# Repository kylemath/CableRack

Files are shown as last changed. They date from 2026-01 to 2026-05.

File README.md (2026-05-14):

# Modular Cable Organizer + Universal Connector System

A wall-mountable, modular cable organizer system designed for 3D printing (PLA+), with an experimental **Universal 24-Pin Connector System** for standardized cable interconnects.

## Project Structure

```
CableRack/
├── parameters.scad           # Central configuration (dimensions, tolerances)
├── insert_base.scad          # Base insert module with snap tabs
├── frame_single.scad         # Single-slot test frame
├── print_frame_2x2.scad      # 2x2 frame (4 slots) - PRODUCTION
├── print_frame_3x3.scad      # 3x3 frame (9 slots) - PRODUCTION
├── print_frame_wall_test.scad          # Wall thickness validation
├── print_frame_validation_test.scad    # Comprehensive test suite
├── insert_*.scad             # All connector insert types
├── print_insert_*.scad       # Print files for each insert
├── demo.scad                 # Demo view with all inserts
│
│── UNIVERSAL CONNECTOR SYSTEM (Experimental)
├── UNIVERSAL_CONNECTOR_SPEC.md    # Full 24-pin specification
├── insert_universal_base.scad     # Universal adapter base module
├── print_insert_universal_*.scad  # Universal adapter print files
├── print_universal_male_terminator.scad  # Cable-end connector
├── demo_universal.scad            # Universal system visualization
│
├── print/                    # Pre-generated STL files
├── ReferenceImages/          # Design reference blueprints
├── UPDATES.md                # Recent changes and improvements
└── README.md                 # This file
```

## Development Status

### ✅ Phase 1-4: COMPLETED
- [x] Parameters system with tolerances
- [x] Snap-fit mechanism with tabs
- [x] Single-slot test frame
- [x] Multi-slot parametric grid frames (2x2, 3x3)
- [x] Wall mounting holes with countersinks
- [x] Complete insert library (9 connector types)
- [x] Production-ready print files

### 🎯 Current Features
- **Frames**: Single (1x1), 2x2 (4 slots), 3x3 (9 slots)
- **Strong walls**: 2.4mm between slots (6 layers @ 0.4mm nozzle)
- **Inserts**: USB-C, USB-A, USB-Mini, USB-Micro, USB-B, Lightning, HDMI, 3.5mm jack, Blank/Label
- **Wall mounting**: 4-corner screw holes with countersinks
- **Snap-fit retention**: Tool-free insert installation/removal

## Print Settings (Recommended)

| Setting | Value |
|---|---|
| Material | PLA+ |
| Layer Height | 0.2mm |
| Nozzle | 0.4mm |
| Infill | 20-30% |
| Walls | 3 perimeters |
| Supports | None needed |

## Production Printing

### Ready-to-Print Files

Pre-generated STL files are in the `print/` directory:

**Frames:**
- `print_frame_single.stl` - 1x1 single slot (test frame)
- `print_frame_2x2.stl` - 2x2 grid (4 slots) - **Most common**
- `print_frame_3x3.stl` - 3x3 grid (9 slots) - NEW

**Inserts:** (9 types)
- `print_insert_usbc.stl` - USB Type-C
- `print_insert_usba.stl` - USB Type-A
- `print_insert_usb_mini.stl` - USB Mini
- `print_insert_micro.stl` - USB Micro
- `print_insert_usb_b.stl` - USB Type-B
- `print_insert_lightning.stl` - Apple Lightning
- `print_insert_hdmi.stl` - HDMI
- `print_insert_audio_jack.stl` - 3.5mm audio jack
- `print_insert_blank.stl` - Blank/label insert

### Test & Validation Files

Before printing production parts, validate with test files:

**Wall Thickness Test** (`print_frame_wall_test.scad`)
- Small print showing 2.4mm wall between slots
- Validates structural strength
- Quick print (~10 min)

**Comprehensive Validation** (`print_frame_validation_test.scad`)
- Wall cross-section view
- Insert fit test with clearances
- Frame size comparison (1x1, 2x2, 3x3)
- Uncomment desired test in file

### Generating STL Files

If you modify the design, regenerate STL files:

```bash
# Using OpenSCAD GUI: File > Export > STL
# Or from terminal:
cd /path/to/CableRack
openscad -o print/print_frame_2x2.stl print_frame_2x2.scad
openscad -o print/print_frame_3x3.stl print_frame_3x3.scad
# etc...
```

### Print Orientation

**Frames**: Print with back (flat) side down
- No supports needed
- Mounting hole countersinks on bottom
- Optimal layer adhesion for strength

**Inserts**: Print with port opening down
- Base plate prints first for dimensional accuracy
- Snap tabs print cleanly
- No supports needed

## Key Dimensions

| Parameter | Value | Description |
|---|---|---|
| Slot size | 32mm × 16mm | Interior frame slot (2:1 aspect) |
| Insert base | 31.4mm × 15.4mm | With 0.3mm clearance |
| **Frame wall** | **2.4mm** | **Between slots (6 layers @ 0.4mm nozzle)** |
| Frame depth | 6mm | Z height (2mm back + 4mm slot) |
| Insert body | 12-16mm | Varies by connector type |
| Clearance | 0.3mm | Standard FDM tolerance |
| Border | 8mm | Frame border with mounting holes |

## Viewing in OpenSCAD

**Demo Visualization** (`demo.scad`)
- Shows 2x2 frame with 4 different inserts
- Displays all 9 insert types in a 3x3 grid
- Toggle `show_cutaway = true` for cross-section view
- Color-coded inserts for easy identification

**Test Files**
- `print_frame_wall_test.scad` - Wall thickness validation
- `print_frame_validation_test.scad` - Multiple test views

## Recent Updates

See `UPDATES.md` for recent changes, including:
- Frame wall thickness increased to 2.4mm (6 layers @ 0.4mm nozzle)
- New 3x3 frame option
- Comprehensive test files for validation
- Improved parametric frame system

---

## Universal Connector System (Experimental)

An ambitious extension to the cable organizer that creates a **standardized 24-pin interconnect** allowing any cable to connect to any device through modular adapters.

### Concept

```
┌─────────────┐     ┌──────────────────┐     ┌─────────────┐
│   DEVICE    │────▶│  24-PIN UNIVERSAL│◀────│   CABLE     │
│  (Laptop)   │     │    INTERFACE     │     │  (Any type) │
└─────────────┘     └──────────────────┘     └─────────────┘
```

### Components

| Component | Description |
|---|---|
| **Device Adapter Insert** | Accepts original connector (USB-C, HDMI, etc.), routes to 24-pin rear |
| **Universal Male Terminator** | Replaces proprietary cable ends with standardized 24-pin plug |
| **Pass-Through Insert** | 24-pin female-to-female for cable extension |

### Protocol Support

| Protocol | Support Level | Notes |
|---|---|---|
| USB 2.0 | ✅ Full | Direct passive routing |
| USB 3.0/3.1 | ✅ Full | Requires impedance-matched PCB |
| USB-C PD (100W) | ✅ Full | With PD controller IC |
| DisplayPort 1.4 | ✅ Full | Native routing, 4 lanes |
| HDMI 1.4 | ⚠️ Active | Requires TMDS↔DP converter |
| Lightning | ✅ Full | USB 2.0 internally |
| 3.5mm Audio | ✅ Full | Analog passthrough |

### Files

- `UNIVERSAL_CONNECTOR_SPEC.md` - Complete 24-pin specification with pinout
- `insert_universal_base.scad` - Base module for all universal adapters
- `print_insert_universal_usbc.scad` - USB-C adapter
- `print_insert_universal_hdmi.scad` - HDMI adapter (active)
- `print_insert_universal_displayport.scad` - DisplayPort adapter
- `print_universal_male_terminator.scad` - Cable-end connector
- `demo_universal.scad` - Visualization and cross-sections

### Certification Path

For production: UL 62368-1, IEC 62368-1, FCC Part 15, CE Mark, RoHS

See `UNIVERSAL_CONNECTOR_SPEC.md` for full technical details.

---

## License

Personal/educational use.

## Preview

<p align="center">
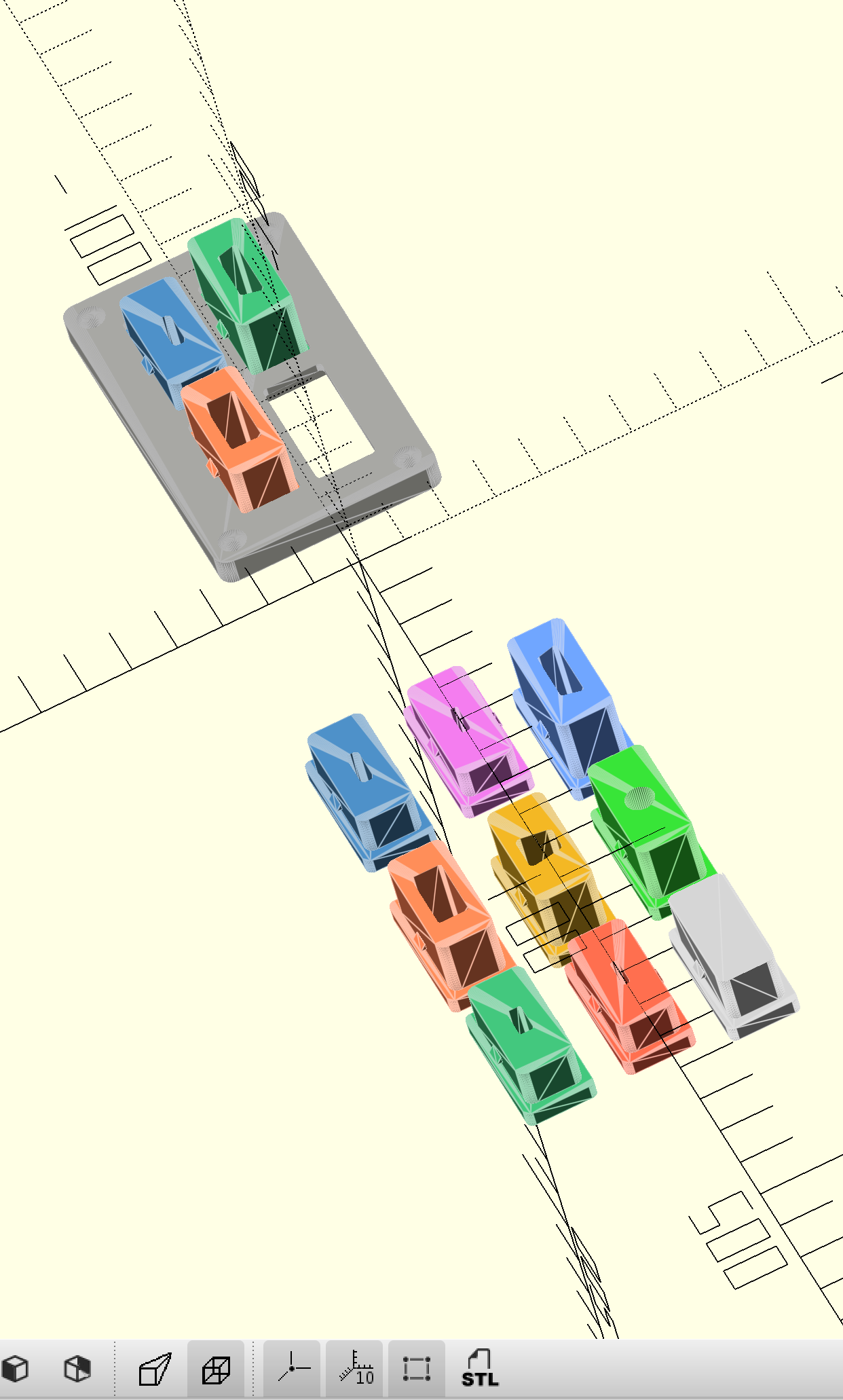
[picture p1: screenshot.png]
Project screenshot
  
</p>

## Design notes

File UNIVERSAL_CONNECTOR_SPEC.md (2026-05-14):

# Universal Connector System Specification

## Vision

A standardized 24-pin interconnect system that enables any cable to connect to any device through modular adapters. Built on the CableRack insert form factor.

## System Overview

```
┌─────────────────┐     ┌─────────────────┐     ┌─────────────────┐
│   DEVICE        │     │   UNIVERSAL     │     │   CABLE         │
│   (Laptop,      │────▶│   24-PIN        │◀────│   (USB-C,       │
│    Phone, TV)   │     │   INTERFACE     │     │    HDMI, etc.)  │
└─────────────────┘     └─────────────────┘     └─────────────────┘
        │                       │                       │
        ▼                       ▼                       ▼
  Original Port          Adapter Insert          Universal Male
  (unchanged)            with routing PCB         Terminator
```

### Components

| Component | Description |
|---|---|
| **Device Adapter Insert** | Accepts original male connector, routes to 24-pin rear interface |
| **Universal Male Terminator** | Replaces proprietary cable ends with standardized 24-pin plug |
| **Pass-Through Insert** | 24-pin female-to-female for cable extension |

---

## 24-Pin Interface Specification

### Physical Dimensions

```
Connector Housing: 16mm × 6mm × 4mm (fits in insert rear)
Pin Pitch: 1.27mm (0.05") - standard fine-pitch
Pin Array: 2 rows × 12 pins
Contact Type: Spring-loaded pogo pins (female) / Gold-plated pads (male)
Insertion Force: <3N
Rated Cycles: 10,000+
```

### Pin Layout (View from rear of insert, looking at female connector)

```
        ┌─────────────────────────────────────────────────────┐
        │  1   2   3   4   5   6   7   8   9  10  11  12      │
  TOP   │  ●   ●   ●   ●   ●   ●   ●   ●   ●   ●   ●   ●      │
  ROW   │ GND VCC VCC D-  D+ SS1 SS1 SS2 SS2 CC1 CC2 SBU     │
        │     5V  20V     TX- TX+ RX- RX+                     │
        ├─────────────────────────────────────────────────────┤
        │ 13  14  15  16  17  18  19  20  21  22  23  24      │
 BOTTOM │  ●   ●   ●   ●   ●   ●   ●   ●   ●   ●   ●   ●      │
  ROW   │ GND GND ML0 ML0 ML1 ML1 ML2 ML2 ML3 ML3 AUX HPD    │
        │         -   +   -   +   -   +   -   +   CH         │
        └─────────────────────────────────────────────────────┘
```

### Pin Definitions

| Pin | Name | Function | Max Rating |
|-----|---|---|---|
| **Power** ||||
| 1 | GND | Ground reference | - |
| 2 | VCC_5V | 5V power rail | 3A (15W) |
| 3 | VCC_HV | High voltage (9V/12V/20V) | 5A (100W) |
| 13 | GND | Ground return (power) | 5A |
| 14 | GND | Ground return (signal) | - |
| **USB 2.0** ||||
| 4 | D- | USB 2.0 Data Minus | 480 Mbps |
| 5 | D+ | USB 2.0 Data Plus | 480 Mbps |
| **USB 3.x SuperSpeed** ||||
| 6 | SSTX- | SuperSpeed TX- | 10 Gbps |
| 7 | SSTX+ | SuperSpeed TX+ | 10 Gbps |
| 8 | SSRX- | SuperSpeed RX- | 10 Gbps |
| 9 | SSRX+ | SuperSpeed RX+ | 10 Gbps |
| **Control** ||||
| 10 | CC1 | Configuration Channel 1 | USB-C negotiation |
| 11 | CC2 | Configuration Channel 2 | USB-C negotiation |
| 12 | SBU | Sideband Use | Alt mode signaling |
| 24 | HPD | Hot Plug Detect | Video presence |
| **Video/Main Link (DisplayPort/HDMI)** ||||
| 15 | ML0- | Main Link Lane 0 - | 8.1 Gbps |
| 16 | ML0+ | Main Link Lane 0 + | 8.1 Gbps |
| 17 | ML1- | Main Link Lane 1 - | 8.1 Gbps |
| 18 | ML1+ | Main Link Lane 1 + | 8.1 Gbps |
| 19 | ML2- | Main Link Lane 2 - | 8.1 Gbps |
| 20 | ML2+ | Main Link Lane 2 + | 8.1 Gbps |
| 21 | ML3- | Main Link Lane 3 - | 8.1 Gbps |
| 22 | ML3+ | Main Link Lane 3 + | 8.1 Gbps |
| 23 | AUX | Auxiliary Channel | DDC/EDID |

---

## Protocol Support Matrix

### Passive Routing (No Active Electronics)

| Protocol | Support | Pins Used | Notes |
|---|---|---|---|
| USB 2.0 | ✅ Full | 1, 4, 5, 13 | Direct wire routing |
| USB 3.0 (5 Gbps) | ✅ Full | 1, 4-9, 13 | Requires impedance matching |
| USB 3.1 (10 Gbps) | ⚠️ Limited | 1, 4-9, 13 | Cable length <1m recommended |
| USB-C PD (100W) | ✅ Full | 1-3, 10-13 | Requires PD controller IC |
| Lightning | ✅ Full | 1, 2, 4, 5, 13 | USB 2.0 internally |
| 3.5mm Audio | ✅ Full | 4, 5, 14 (repurposed) | Analog, no data |
| DisplayPort 1.2 | ✅ Full | 13-24 | 4 lanes @ 5.4 Gbps |
| DisplayPort 1.4 | ⚠️ Limited | 13-24 | 4 lanes @ 8.1 Gbps, short cables |
| HDMI 1.4 | ⚠️ Requires conversion | 13-24 | TMDS ↔ DP conversion needed |
| HDMI 2.0+ | ❌ Active required | - | Needs protocol converter IC |
| Thunderbolt | ❌ Not supported | - | Active cables, authentication |
| Ethernet | ❌ Not supported | - | Would need 8 dedicated pairs |

### Active Adapters (With Embedded Electronics)

For HDMI support, adapter inserts would contain:
- TMDS to DisplayPort level shifter IC
- EDID EEPROM
- 3.3V regulator

---

## Insert Design Specifications

### Device Adapter Insert (Female Original → 24-Pin Female Rear)

```
FRONT VIEW                         SIDE CROSS-SECTION
┌────────────────────┐            ┌────────────────────┐
│  ┌──────────────┐  │            │▓▓▓▓▓▓▓▓▓▓▓▓▓▓▓▓▓▓▓▓│ ← Shell
│  │   Original   │  │            │  ┌──────────────┐  │
│  │  Connector   │  │            │  │   Connector  │══╪═► Cable plugs here
│  │   Opening    │  │            │  │    Socket    │  │
│  └──────────────┘  │            │  └──────┬───────┘  │
│                    │            │         │ PCB      │
│  ┌──────────────┐  │            │  ┌──────┴───────┐  │
│  │  [24-pin]    │  │            │  │ Signal Route │  │
│  │   Female     │  │            │  │    Board     │  │
│  └──────────────┘  │            │  └──────┬───────┘  │
│ [snap]      [snap] │            │  ┌──────┴───────┐  │
└────────────────────┘            │  │  24-Pin Conn │◀═╪═ Universal cable
                                  │  └──────────────┘  │
                                  └────────────────────┘
```

### Internal PCB Specifications

| Parameter | Wide Insert | Narrow Insert |
|---|---|---|
| Max PCB Size | 26mm × 11mm | 10mm × 11mm |
| PCB Thickness | 1.0mm (4-layer) | 0.8mm (4-layer) |
| Layer Stack | SIG-GND-GND-SIG | SIG-GND-GND-SIG |
| Impedance | 90Ω differential | 90Ω differential |
| Trace Width | 0.15mm (diff pairs) | 0.12mm (diff pairs) |
| Via Size | 0.3mm drill | 0.25mm drill |

### Signal Integrity Requirements

For high-speed video (8+ Gbps per lane):
- Differential pair impedance: 90Ω ±10%
- Insertion loss: <3dB at 4 GHz
- Return loss: >15dB
- Crosstalk: <-30dB
- Length matching: ±0.5mm within pairs

---

## Universal Male Terminator

The cable-side connector that replaces original plugs:

```
┌─────────────────────────────────────┐
│          CABLE ENTRY                │
│              ║                      │
│         ┌────╨────┐                 │
│         │  Strain │                 │
│         │  Relief │                 │
│         └────┬────┘                 │
│         ┌────┴────┐                 │
│         │  Wire   │                 │
│         │ Routing │                 │
│         │   PCB   │                 │
│         └────┬────┘                 │
│         ┌────┴────┐                 │
│         │ 24-Pin  │                 │
│         │  Male   │●●●●●●●●●●●●     │
│         │ Contact │●●●●●●●●●●●●     │
│         └─────────┘                 │
└─────────────────────────────────────┘

Dimensions: 20mm × 8mm × 6mm
```

### Wire Gauge Requirements

| Function | AWG | Max Current | Max Length |
|---|-----|---|---|
| Power (100W) | 18 | 5A | 2m |
| Power (60W) | 20 | 3A | 2m |
| USB 2.0 Data | 28 | - | 5m |
| USB 3.x Data | 26 (shielded) | - | 2m |
| Video Lanes | 26 (shielded) | - | 2m |
| Ground | 18 | 5A | 2m |

---

## Connector Routing Tables

### USB-C Adapter (Full Featured)

| USB-C Pin | Function | → 24-Pin |
|---|---|---|
| A1, B1, A12, B12 | GND | 1, 13, 14 |
| A4, B4 | VBUS | 2, 3 |
| A5 | CC1 | 10 |
| B5 | CC2 | 11 |
| A6, B6 | D+ | 5 |
| A7, B7 | D- | 4 |
| A2 | SSTX1+ | 7 |
| A3 | SSTX1- | 6 |
| B10 | SSRX2+ | 9 |
| B11 | SSRX2- | 8 |
| A8 | SBU1 | 12 |
| B8 | SBU2 | 12 |

### HDMI Adapter (Requires Active Conversion)

| HDMI Pin | Function | → 24-Pin (via converter) |
|---|---|---|
| 1, 2, 3 | TMDS Data2 | ML2+, ML2- (converted) |
| 4, 5, 6 | TMDS Data1 | ML1+, ML1- (converted) |
| 7, 8, 9 | TMDS Data0 | ML0+, ML0- (converted) |
| 10, 11, 12 | TMDS Clock | (embedded in DP stream) |
| 13 | CEC | Not mapped |
| 14 | Reserved | - |
| 15, 16 | DDC | AUX |
| 17 | GND | 13, 14 |
| 18 | +5V | 2 |
| 19 | HPD | 24 |

### DisplayPort Adapter (Native)

| DP Pin | Function | → 24-Pin |
|---|---|---|
| 1, 3 | ML0+, ML0- | 16, 15 |
| 4, 6 | ML1+, ML1- | 18, 17 |
| 7, 9 | ML2+, ML2- | 20, 19 |
| 10, 12 | ML3+, ML3- | 22, 21 |
| 15, 17 | AUX+, AUX- | 23 |
| 18 | HPD | 24 |
| 2, 5, 8, 11, 14 | GND | 13, 14 |
| 20 | DP_PWR | 2 |

### USB-A 3.0 Adapter

| USB-A Pin | Function | → 24-Pin |
|---|---|---|
| 1 | VBUS | 2 |
| 2 | D- | 4 |
| 3 | D+ | 5 |
| 4 | GND | 1 |
| 5 | SSRX- | 8 |
| 6 | SSRX+ | 9 |
| 7 | GND_DRAIN | 13 |
| 8 | SSTX- | 6 |
| 9 | SSTX+ | 7 |

### Lightning Adapter (USB 2.0 + Charging)

| Lightning Pin | Function | → 24-Pin |
|---|---|---|
| 1 | GND | 1, 13 |
| 2 | L0p (Data) | 5 |
| 3 | L0n (Data) | 4 |
| 4 | ID0 | 10 |
| 5 | PWR | 2 |
| 6 | L1n | NC |
| 7 | L1p | NC |
| 8 | ID1 | 11 |

### 3.5mm Audio Jack (TRS/TRRS)

| Ring | Function | → 24-Pin |
|---|---|---|
| Tip | Left / Mono | 4 (repurposed) |
| Ring 1 | Right | 5 (repurposed) |
| Ring 2 | Mic (TRRS) | 12 (repurposed) |
| Sleeve | Ground | 14 |

---

## Bill of Materials (Per Adapter Type)

### Passive USB-C Adapter

| Component | Qty | Est. Cost |
|---|-----|---|
| 24-pin female connector | 1 | $0.80 |
| USB-C receptacle | 1 | $0.50 |
| 4-layer PCB (26×11mm) | 1 | $0.30 |
| 3D printed housing | 1 | $0.20 |
| **Total** | | **~$1.80** |

### Active HDMI Adapter

| Component | Qty | Est. Cost |
|---|-----|---|
| 24-pin female connector | 1 | $0.80 |
| HDMI Type-A receptacle | 1 | $0.60 |
| TMDS-to-DP converter IC | 1 | $3.50 |
| 3.3V LDO regulator | 1 | $0.15 |
| Passives (caps, resistors) | ~10 | $0.20 |
| 4-layer PCB | 1 | $0.50 |
| 3D printed housing | 1 | $0.20 |
| **Total** | | **~$5.95** |

### Universal Male Terminator

| Component | Qty | Est. Cost |
|---|-----|---|
| 24-pin male contact array | 1 | $1.00 |
| 2-layer routing PCB | 1 | $0.20 |
| Strain relief | 1 | $0.15 |
| Overmolded housing | 1 | $0.30 |
| **Total** | | **~$1.65** |

---

## Certification Requirements

### Safety & EMC

| Certification | Scope | Requirement |
|---|---|---|
| UL 62368-1 | Audio/Video/IT equipment | Required for US/Canada |
| IEC 62368-1 | International safety | Required for EU/intl |
| FCC Part 15 | EMC (USA) | Required |
| CE Mark | EMC + Safety (EU) | Required |
| RoHS | Hazardous substances | Required |

### Protocol Compliance (Optional but Recommended)

| Certification | Fee Range | Notes |
|---|---|---|
| USB-IF | $5,000+ | Required to use USB logo |
| HDMI Licensing | $10,000+/yr | Required to use HDMI trademark |
| DisplayPort | Included in VESA membership | ~$5,000/yr |

---

## Development Phases

### Phase 1: Proof of Concept
- [ ] Design 24-pin connector footprint
- [ ] Modify insert_base.scad for PCB cavity
- [ ] Create USB-C passive adapter insert
- [ ] Create universal male terminator housing
- [ ] Test USB 2.0 + power delivery

### Phase 2: High-Speed Data
- [ ] Design impedance-controlled PCBs
- [ ] USB 3.0 adapter insert
- [ ] DisplayPort adapter insert (native routing)
- [ ] Signal integrity testing

### Phase 3: Video Support
- [ ] HDMI active adapter (with converter IC)
- [ ] Full DisplayPort 1.4 validation
- [ ] Multi-protocol cable assemblies

### Phase 4: Certification & Production
- [ ] EMC pre-compliance testing
- [ ] Safety certification
- [ ] Injection-molded housings
- [ ] Production tooling

---

## Open Questions

1. **Connector gender convention**: Should the "frame side" always be female?
2. **Keying**: Add physical keying to prevent misalignment?
3. **Locking mechanism**: Friction fit or latching?
4. **Hot-swap protection**: Add TVS diodes for ESD?
5. **Power negotiation**: Embed USB-C PD controller in every adapter?

---

## References

- USB Type-C Specification Rev 2.1
- USB Power Delivery Specification Rev 3.1
- DisplayPort Standard 1.4a
- HDMI Specification 2.1
- USB-IF Cable and Connector Class Documents

---

*Document Version: 0.1 (Draft)*
*Last Updated: 2026-01-25*

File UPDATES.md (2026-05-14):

# Frame Wall Thickness Update

## Date: January 24, 2026

### Problem Identified
The 2x2 frame had insufficient wall thickness between slots:
- Previous `frame_wall` value: **0.5mm** (approximately 1 layer with 0.4mm nozzle)
- This was too thin for structural integrity
- Walls would be weak and prone to failure

### Solution Implemented
Increased wall thickness for proper strength:
- New `frame_wall` value: **2.4mm** (6 layers with 0.4mm nozzle)
- This provides adequate structural strength between slots
- Maintains all clearances for inserts

### Changes Made

#### 1. Updated `parameters.scad`
- Increased `frame_wall` from 0.5mm to 2.4mm
- Updated comments to clarify this provides 6 layers at 0.4mm nozzle width
- Grid parameters (grid_cols, grid_rows) can now be overridden in individual files

#### 2. Refactored Frame Files
Updated all frame files to use parametric calculations:
- `print_frame_2x2.scad` - Now calculates dimensions locally
- `demo.scad` - Updated to match new structure
- `print_test_set.scad` - Updated with proper frame calculations

#### 3. Created New Files

**`print_frame_3x3.scad`**
- New 3x3 frame (9 slots total)
- Uses same parametric structure as 2x2
- Includes mounting holes with countersinks
- Print with back side down (no supports needed)

**`print_frame_wall_test.scad`**
- Test file to visualize wall thickness
- Shows 2 adjacent slots with wall between them
- Can display with or without inserts for clearance validation
- Includes measurement helpers

**`print_frame_validation_test.scad`**
- Comprehensive validation suite
- Shows wall thickness cross-section
- Insert fit test with clearance highlighting
- Frame size comparison (1x1, 2x2, 3x3)
- Parametric frame generator for testing

### Design Validation

#### Wall Thickness
- **6 layers @ 0.4mm nozzle = 2.4mm wall**
- Provides strong structural integrity
- Walls won't flex or break during insert installation/removal

#### Insert Clearances
All insert clearances remain intact:
- `clearance = 0.3mm` (unchanged)
- `insert_body_width` and `insert_body_height` clearances preserved
- Snap tab clearances maintained
- Back cutouts properly sized

#### Frame Dimensions (Updated)
With 2.4mm walls, the frame dimensions are now:
- **2x2 Frame**: ~72mm × ~42mm × 6mm (increased from ~69mm × ~40mm)
- **3x3 Frame**: ~109mm × ~58mm × 6mm
- Border: 8mm (unchanged)
- Back thickness: 2mm (unchanged)

### Testing Recommendations

1. **Print Wall Test**
   - Open `print_frame_wall_test.scad`
   - Renders a small section showing the 2.4mm wall
   - Quick print to validate strength

2. **Print Validation Test**
   - Open `print_frame_validation_test.scad`
   - Uncomment desired test (wall thickness, insert fit, or comparison)
   - Visual verification of all improvements

3. **Print Updated Frames**
   - `print_frame_2x2.scad` - Now with strong walls
   - `print_frame_3x3.scad` - New 3x3 grid option
   - Both ready for production printing

### Files Modified
- `parameters.scad` - Increased frame_wall to 2.4mm
- `print_frame_2x2.scad` - Refactored with parametric dimensions
- `demo.scad` - Updated frame module structure
- `print_test_set.scad` - Updated frame module structure

### Files Created
- `print_frame_3x3.scad` - New 3x3 frame
- `print_frame_wall_test.scad` - Wall thickness test
- `print_frame_validation_test.scad` - Comprehensive validation suite

### Next Steps
1. Generate STL files for the updated frames
2. Test print to validate the 2.4mm wall strength
3. Verify insert fit remains correct
4. Consider creating additional frame sizes (1x3, 2x3, etc.) using the parametric approach

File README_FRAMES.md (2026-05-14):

# CableRack Frame Sizes

All frame files use the parameterized `frame_module.scad` and can be rendered with any row/column combination.

## Pre-configured Frame Sizes

| File | Size | Slots | Dimensions (approx) | Notes |
|---|---|---|---|---|
| `print_frame_single.scad` | 1×1 | 1 | 48.5 × 32.5 mm | Minimal single slot |
| `print_frame_2x2.scad` | 2×2 | 4 | 80.5 × 48.5 mm | Original test size |
| `print_frame_4x4.scad` | 4×4 | 16 | 145 × 80.5 mm | Small rack |
| `print_frame_6x6.scad` | 6×6 | 36 | 209 × 112.5 mm | Medium rack |
| `print_frame_8x15.scad` | 8×15 | 120 | 275 × 256.5 mm | Large balanced rack |
| `print_frame_10x10.scad` | 10×10 | 100 | 340.5 × 176.5 mm | Wide rack |
| `print_frame_10x20.scad` | 10×20 | 200 | 340.5 × 336.5 mm | **Maximum for 350mm bed** |

## Custom Frame Sizes

Use `print_frame_CUSTOM.scad` to create any size:

1. Open `print_frame_CUSTOM.scad`
2. Edit the `cols` and `rows` values (lines 18-19)
3. Render and export to STL

### Frame Size Calculator

**Width** = (cols × 32.5) + 16 mm  
**Height** = (rows × 16.5) + 16 mm

### 350×350mm Bed Limits

- **Maximum columns:** 10 (340.5mm width)
- **Maximum rows:** 20 (345.5mm height)
- **Maximum slots:** 200 (10×20 grid)

## Examples for Common Bed Sizes

### 220×220mm bed (Ender 3, etc.)
- 6×12 grid → 209 × 208.5 mm (72 slots)
- 6×10 grid → 209 × 176.5 mm (60 slots)

### 250×250mm bed
- 7×14 grid → 243.5 × 241.5 mm (98 slots)
- 7×12 grid → 243.5 × 208.5 mm (84 slots)

### 300×300mm bed
- 8×17 grid → 275 × 296.5 mm (136 slots)
- 9×17 grid → 308.5 × 296.5 mm (153 slots)

### 350×350mm bed
- 10×15 grid → 340.5 × 256.5 mm (150 slots)
- 10×20 grid → 340.5 × 336.5 mm (200 slots) **MAXIMUM**

## Creating Your Own Print File

```openscad
// my_custom_frame.scad
include <frame_module.scad>

// 7×12 frame for my specific needs
grid_frame(cols=7, rows=12);
```

## Technical Details

All frames include:
- Mounting holes in corners with countersinks
- Back cutouts to save filament
- Snap-fit slots for inserts
- No supports needed (print with back side down)

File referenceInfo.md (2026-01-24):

Create a technical blueprint in a classic with a white and black lines engineering style for a modular, wall-mountable cable organizer. The image should display a flat, orthographic view of a main "Grid Frame" featuring a symmetrical matrix of empty square slots (rows and columns) designed to hold interchangeable inserts. The piece should have 300 x 300 dimensions for the outer frame and the frame should be flat on the face that will sit on the print bed 

Alongside the frame, provide detailed technical breakouts for 9 specific interchangeable insert modules that securely but reversibly snap into the grid. :1. USB-C female holder2. USB Mini female holder3. Lightning female holder4. USB-A female holder 5. USB-B Female Holder 6. 3.55 mm female jack holder 7. HDMI port and 8.  MicoUSB, and 9. A blank/label plate for identification
The male cable ends will plug into these pieces, and so they should be raised up higher than the frame they fit into so that there is clearance within the piece and frame area for the male cable section. 

The visual style must be high-contrast and precise, suitable for a mechanical engineer to use as a reference for creating a printable 3D object use PLA+. Include schematic dimension lines, technical annotations, and clear separation between the frame assembly and the individual insert component views. Make precise models of the module frame interface and attachement components and consider layer line weaknesses when designing the mechanism. This will be used to make autocad .scad model of the parts so keep the printing process in mind when designing.

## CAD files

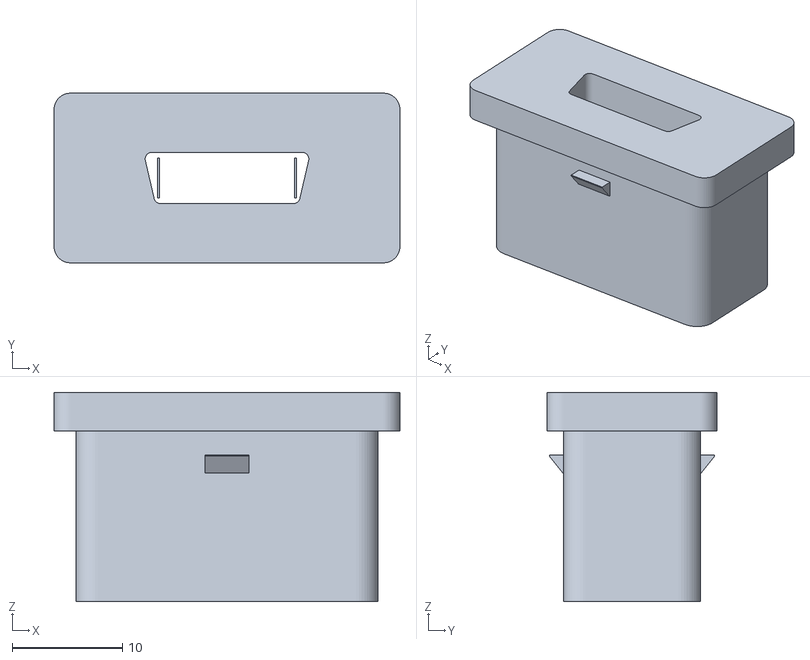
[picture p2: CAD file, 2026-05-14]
print/print_insert_hdmi.stl
31.4 x 15.4 x 19.0

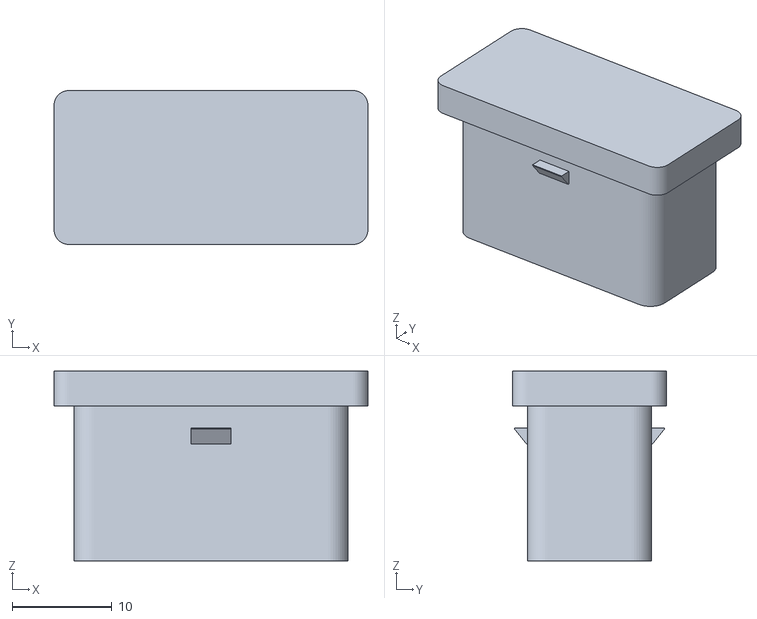
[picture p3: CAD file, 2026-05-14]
print/print_insert_blank.stl
31.4 x 15.4 x 19.0

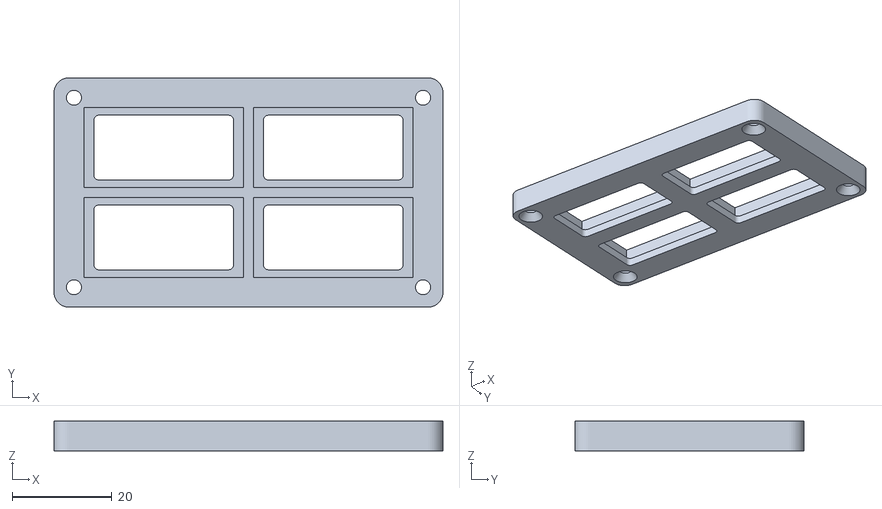
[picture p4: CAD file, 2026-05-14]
print/print_frame_2x2.stl
78.0 x 46.0 x 6.00

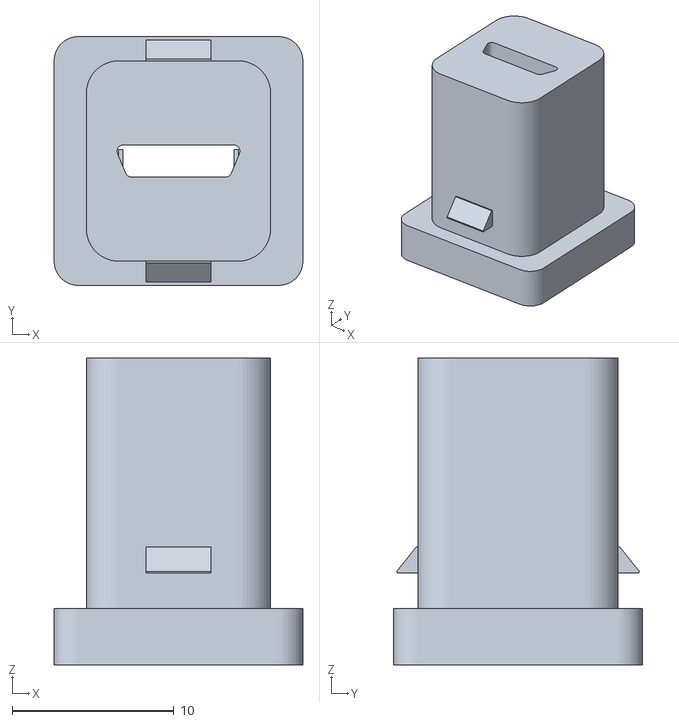
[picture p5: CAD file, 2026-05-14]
print/print_insert_micro_narrow.stl
15.4 x 15.4 x 19.0

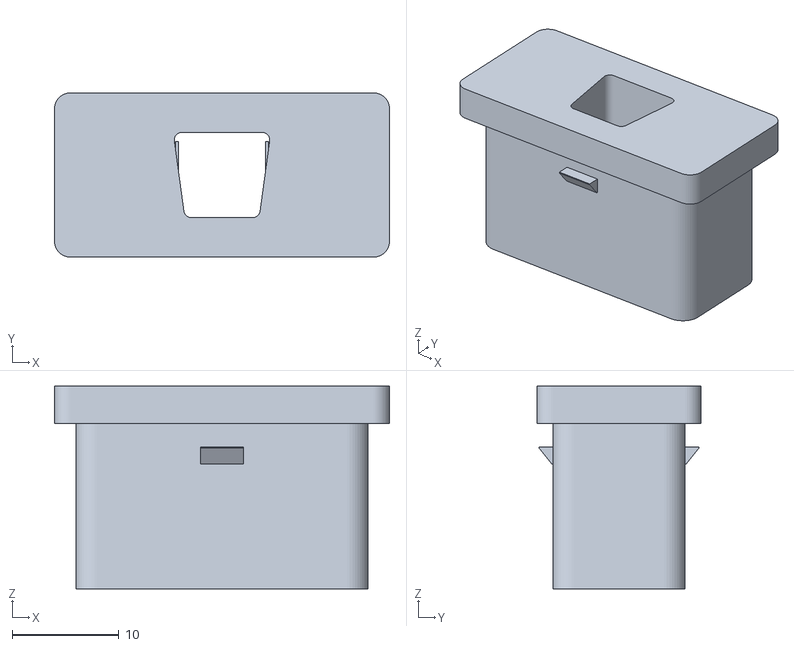
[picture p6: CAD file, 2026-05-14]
print/print_insert_usb_b.stl
31.4 x 15.4 x 19.0

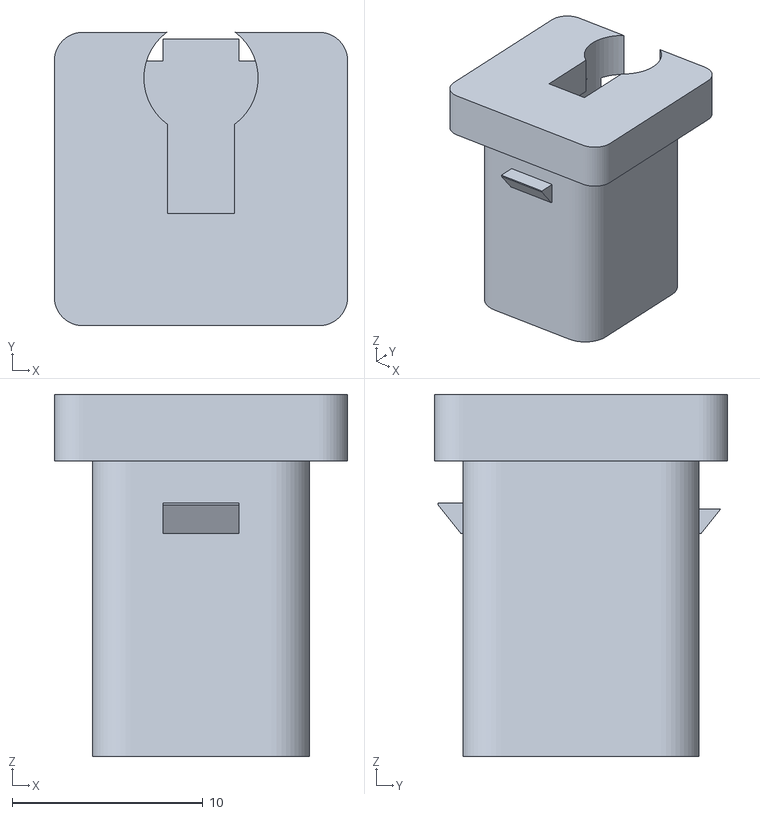
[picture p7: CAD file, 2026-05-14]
print/print_insert_mount_narrow.stl
15.4 x 15.4 x 19.0

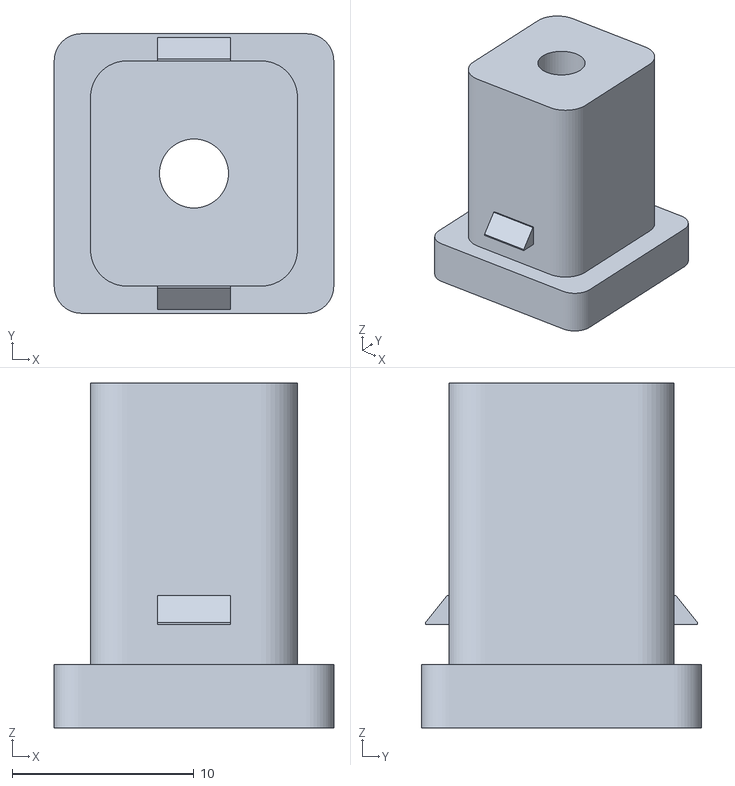
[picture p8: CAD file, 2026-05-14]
print/print_insert_audio_jack_narrow.stl
15.4 x 15.4 x 19.0

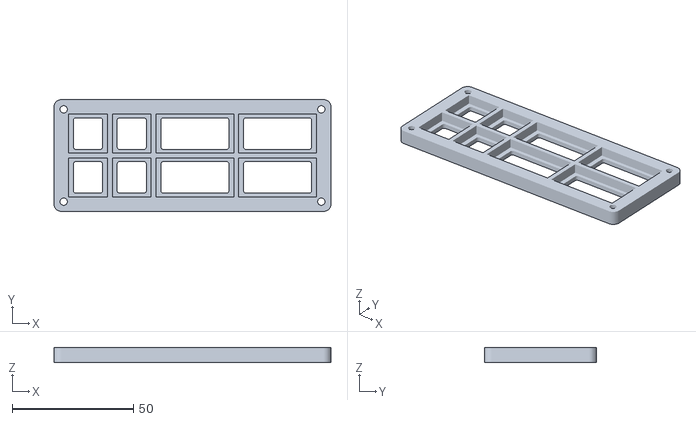
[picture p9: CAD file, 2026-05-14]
print/print_frame_mixed_2n2w_2rows.stl
114.0 x 46.0 x 6.00

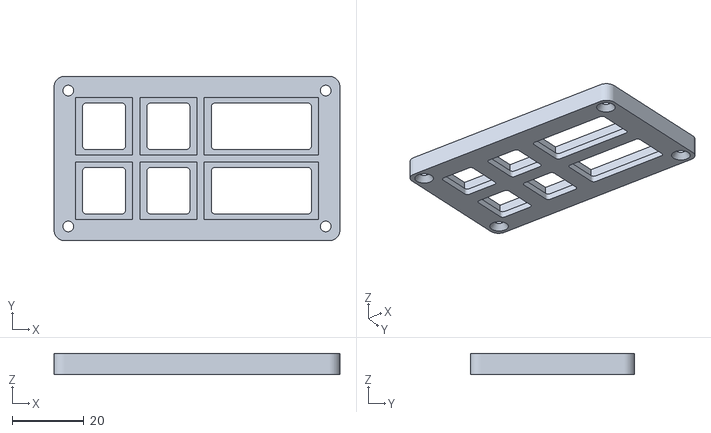
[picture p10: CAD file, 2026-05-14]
print/print_frame_mixed_2n1w_2rows.stl
80.0 x 46.0 x 6.00

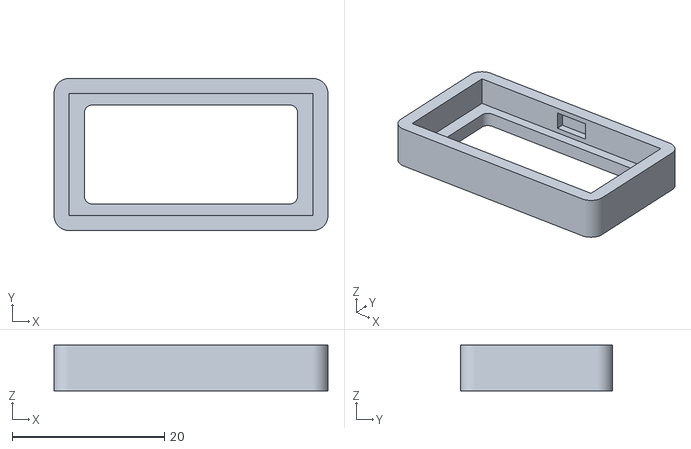
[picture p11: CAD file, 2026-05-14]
print/print_frame_single.stl
36.0 x 20.0 x 6.00

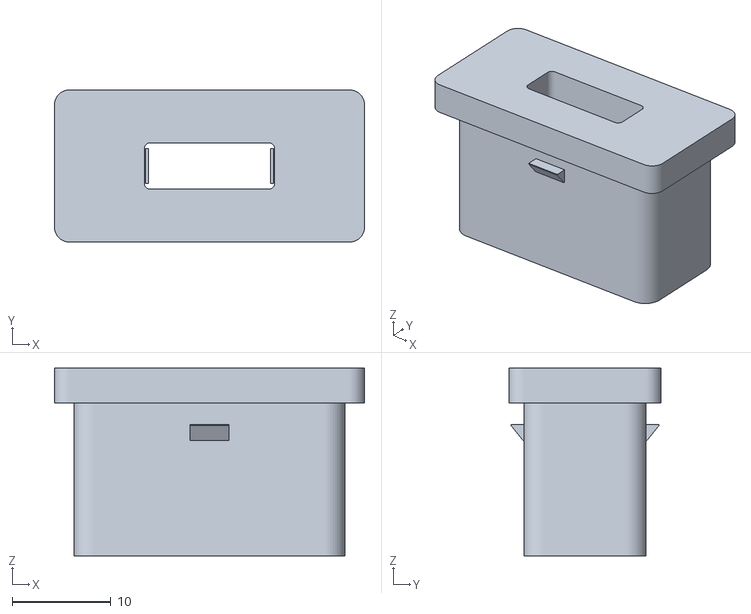
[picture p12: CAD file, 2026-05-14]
print/print_insert_usba.stl
31.4 x 15.4 x 19.0

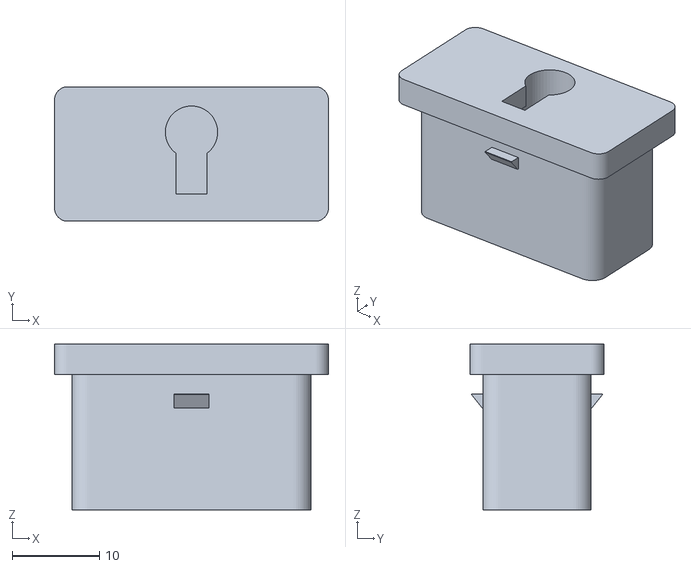
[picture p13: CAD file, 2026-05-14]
print/print_insert_mount.stl
31.4 x 15.4 x 19.0

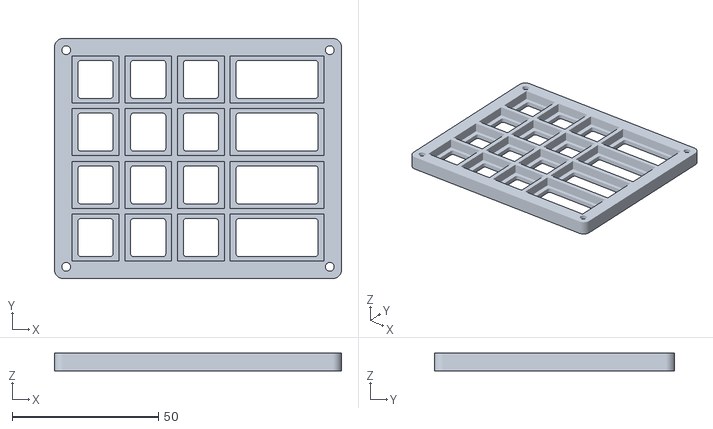
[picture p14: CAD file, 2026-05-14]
print/print_frame_mixed_4n_3rows.stl
98.0 x 82.0 x 6.00

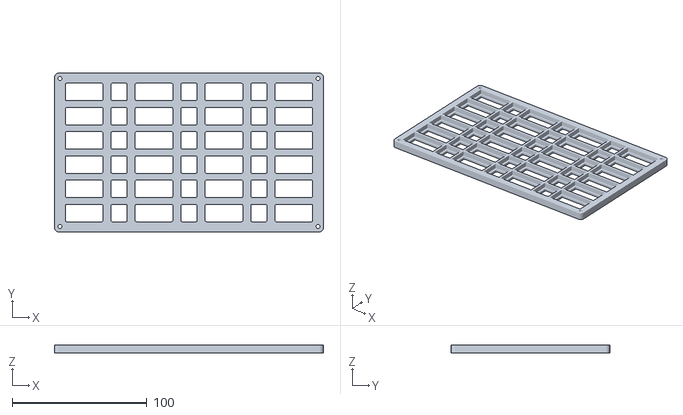
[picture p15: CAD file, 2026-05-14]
print/print_frame_mixed_7x6mixed.stl
200.0 x 118.0 x 6.00

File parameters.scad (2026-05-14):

// ============================================
// MODULAR CABLE ORGANIZER - SHARED PARAMETERS
// ============================================
// All dimensions in mm - include this in all files
// ============================================

$fn = 48;

// === TOLERANCES ===
clearance = 0.3;
port_clearance = 0.1;  // Extra clearance for port openings (reduced - 0.2 was too loose for USB-C)
wall = 1.6;

// === SLOT DIMENSIONS (2:1 aspect ratio) - scaled to 2/3 ===
slot_width = 32;  // Standard wide slot for larger connectors
slot_width_narrow = 16;  // Narrow slot for compact connectors (USB-C, micro-USB, USB-A, Lightning, 3.5mm)
slot_height = 16;  // Height is same for both wide and narrow
slot_depth = 4;  // Reduced from 6mm - less frame depth needed

// === FRAME STRUCTURE ===
frame_wall = 2.0;   // Wall between slots - 6 layers @ 0.4mm nozzle for strength
frame_border = 6;  // Increased by 10mm for mounting holes with countersink
frame_back = 2;     // Slightly thicker for snap catch strength
mount_hole_dia = 4;  // M4 mounting holes (changed from M3 for common screw sizes)
countersink_dia = 8;  // Diameter of countersink for M4 screw heads
countersink_depth = 2;  // Depth of countersink

// === DEFAULT GRID (can be overridden in individual files) ===
grid_cols = 2;
grid_rows = 2;

// === INSERT BASE DIMENSIONS ===
insert_width = slot_width - (2 * clearance);
insert_height = slot_height - (2 * clearance);
insert_base_depth = slot_depth - 0.5;

// === NARROW INSERT BASE DIMENSIONS ===
insert_width_narrow = slot_width_narrow - (2 * clearance);
insert_height_narrow = slot_height - (2 * clearance);

// === INSERT BODY (protrudes from frame) ===
insert_body_width = insert_width - 4;
insert_body_height = insert_height - 3;
insert_body_depth = 15.5;  // Standardized depth (USB-B 15.26mm + 0.25mm buffer) - all inserts same height
insert_top_thick = 1.5;  // Top platform thickness

// === NARROW INSERT BODY (protrudes from frame) ===
insert_body_width_narrow = insert_width_narrow - 4;
insert_body_height_narrow = insert_height_narrow - 3;

// === SNAP TABS (on neck/body - catch on back plate) ===
snap_tab_width = 4;
snap_tab_protrude = 1.2;  // How far tab sticks out from body
snap_tab_thick = 1.5;     // Z thickness of tab
snap_tab_offset = 2.2;      // Distance from base to tab bottom on insert (increased to clear frame)

// === CONNECTOR PORT DIMENSIONS & BODY DEPTHS ===
// Port dimensions from reference blueprints
// Body depths sized to match typical male connector lengths

// USB-C: 8.4 x 2.6mm, male connector ~9mm
usbc_w = 8.4;
usbc_h = 2.6;
usbc_r = 1.0;
usbc_body_depth = 15.5;  // Standardized depth (USB-B 15.26mm + 0.25mm buffer)
// NO RETENTION RIBS for USB-C (removed per user request)

// USB-A: 13.0 x 4.5mm (standard male USB-A height)
usba_w = 13.0;
usba_h = 4.5;  // Match actual male USB-A height
usba_r = 0.5;
usba_body_depth = 15.5;  // Standardized depth (USB-B 15.26mm + 0.25mm buffer)
usba_retention_rib_depth = 5.0;  // Distance from front (moved back 1mm so ribs don't break)
usba_retention_rib_size = 0.15;  // How far ribs protrude inward

// USB Mini: 6.9 x 3.0mm, male connector ~9mm
usb_mini_w = 6.9;
usb_mini_h = 3.0;
usb_mini_r = 0.5;
usb_mini_body_depth = 15.5;  // Standardized depth (USB-B 15.26mm + 0.25mm buffer)
usb_mini_retention_rib_depth = 3.5;  // Distance from front where retention ribs start
usb_mini_retention_rib_size = 0.125;  // Reduced to half (was 0.25)

// USB Micro-B: 7.4 x 1.8mm (wider to fit corners of trapezoid)
usb_micro_w = 7.4;  // Increased width for corners
usb_micro_h = 1.8;
usb_micro_r = 0.3;
usb_micro_body_depth = 15.5;  // Standardized depth (USB-B 15.26mm + 0.25mm buffer)
usb_micro_retention_rib_depth = 4.5;  // Distance from front (moved back 1mm so ribs don't break)
usb_micro_retention_rib_size = 0.125;  // How far ribs protrude inward

// USB-B: 8.75 x 7.78mm (standard male USB-B height)
usb_b_w = 8.75;  // Width at bottom (wider)
usb_b_h = 7.78;  // Match actual male USB-B height (reduced from 7.9)
usb_b_r = 0.6;   // Corner radius
usb_b_top_inset = 0.9;  // How much narrower the top is (creates trapezoid shape)
usb_b_body_depth = 15.5;  // Standardized depth (15.26mm connector + 0.25mm buffer)
usb_b_retention_rib_depth = 5.5;  // Distance from front (moved back 1mm so ribs don't break)
usb_b_retention_rib_size = 0.15;  // How far ribs protrude inward

// Lightning: 7.6 x 1.5mm, male connector ~8mm (measured from actual connector)
lightning_w = 7.6;
lightning_h = 1.5;
lightning_r = 0.5;
lightning_body_depth = 15.5;  // Standardized depth (USB-B 15.26mm + 0.25mm buffer)
lightning_retention_rib_depth = 4.0;  // Distance from front (moved back 1mm so ribs don't break)
lightning_retention_rib_size = 0.1;   // How far ribs protrude inward

// HDMI: 14.65 x 4.45mm (standard male HDMI height)
hdmi_w = 14.65;
hdmi_h = 4.45;  // Match actual male HDMI height
hdmi_r = 0.5;
hdmi_body_depth = 15.5;  // Standardized depth (USB-B 15.26mm + 0.25mm buffer)
hdmi_retention_rib_depth = 6.0;  // Distance from front (moved back 1mm so ribs don't break)
hdmi_retention_rib_size = 0.1;   // How far ribs protrude inward

// 3.5mm Audio Jack: standard 3.5mm (1/8") diameter
audio_jack_dia = 3.6;  // 3.5mm + 0.1mm for less snug fit
audio_jack_body_depth = 15.5;  // Standardized depth (USB-B 15.26mm + 0.25mm buffer)
// Ring positions for TRS/TRRS ribs (tip, ring1, ring2 from front)
audio_jack_ring1 = 3.5;  // First ring position from front
audio_jack_ring2 = 6.5;  // Second ring position from front

// Blank/Label: recessed area for label
label_w = 30;
label_h = 12;
label_depth = 0.8;

// Keyhole mounting slot: picture-hanger style for wall/table mounting
// The keyhole allows a round-headed screw to pass through, then lock in slot
keyhole_head_dia = 6;   // Diameter for screw head to pass through (5% narrower, fits #6-#8 wood screws)
keyhole_slot_width = 3.5; // Width of slot for screw shaft
keyhole_slot_length = 5.3; // Travel distance to lock screw in place
keyhole_depth = 2.5;      // Depth of keyhole cut (allows screw head to sit below surface)

// AC Power Plug: asymmetric holes for polarity (US 2-prong)
// Prongs are VERTICAL (tall and thin)
// Hot prong (narrower): 1.6mm wide x 6.5mm tall
// Neutral prong (wider): 1.6mm wide x 8.5mm tall (increased)
power_hot_w = 1.6;   // Width (thin dimension)
power_hot_h = 6.5;   // Height (tall dimension)
power_neutral_w = 1.6;   // Width (thin dimension)
power_neutral_h = 8.5;   // Height (tall dimension, increased from 8.1)
power_prong_spacing = 12.7;  // 0.5" center-to-center
power_body_depth = 15.5;  // Standardized depth (USB-B 15.26mm + 0.25mm buffer)

// === CALCULATED VALUES ===
frame_total_depth = frame_back + slot_depth;
grid_width = (grid_cols * slot_width) + ((grid_cols - 1) * frame_wall);
grid_height = (grid_rows * slot_height) + ((grid_rows - 1) * frame_wall);
frame_width = grid_width + (2 * frame_border);
frame_height_total = grid_height + (2 * frame_border);
insert_total_depth = insert_base_depth + insert_body_depth;

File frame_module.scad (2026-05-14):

// ============================================
// PARAMETERIZED FRAME MODULE
// ============================================
// Call grid_frame(cols, rows) to generate any size frame
// ============================================

include <parameters.scad>

// === PARAMETERIZED FRAME FUNCTION ===
module grid_frame(cols=2, rows=2) {
    // Calculate dimensions based on parameters
    local_grid_width = (cols * slot_width) + ((cols - 1) * frame_wall);
    local_grid_height = (rows * slot_height) + ((rows - 1) * frame_wall);
    local_frame_width = local_grid_width + (2 * frame_border);
    local_frame_height = local_grid_height + (2 * frame_border);
    
    difference() {
        rounded_box_rect(local_frame_width, local_frame_height, frame_total_depth, 3);
        translate([0, 0, frame_back]) slot_grid(cols, rows);
        back_cutouts(cols, rows);
        mounting_holes(local_frame_width, local_frame_height);
    }
}

module slot_grid(cols, rows) {
    for (col = [0 : cols-1], row = [0 : rows-1]) {
        x = (col - (cols-1)/2) * (slot_width + frame_wall);
        y = (row - (rows-1)/2) * (slot_height + frame_wall);
        translate([x, y, 0]) slot_recess();
    }
}

module slot_recess() {
    translate([0, 0, slot_depth/2 + 0.1])
        cube([slot_width, slot_height, slot_depth + 0.2], center=true);
}

module back_cutouts(cols, rows) {
    cutout_w = insert_body_width + 2*clearance;
    cutout_h = insert_body_height + 2*clearance;
    
    for (col = [0 : cols-1], row = [0 : rows-1]) {
        x = (col - (cols-1)/2) * (slot_width + frame_wall);
        y = (row - (rows-1)/2) * (slot_height + frame_wall);
        translate([x, y, -0.1])
            rounded_box_rect(cutout_w, cutout_h, frame_back + 0.2, 1);
    }
}

module mounting_holes(fw, fh) {
    hx = fw/2 - frame_border/2;
    hy = fh/2 - frame_border/2;
    for (xm = [-1, 1], ym = [-1, 1]) {
        translate([xm * hx, ym * hy, -0.1]) {
            // Through hole for screw shaft
            cylinder(d=mount_hole_dia, h=frame_total_depth + 0.2);
            // Countersink on back face (mounting surface)
            cylinder(d1=countersink_dia, d2=mount_hole_dia, h=countersink_depth);
        }
    }
}

// === HELPER MODULE FOR ROUNDED BOX (if not in parameters.scad) ===
module rounded_box_rect(w, h, d, r) {
    hull() {
        for (x = [-(w/2-r), (w/2-r)])
            for (y = [-(h/2-r), (h/2-r)])
                translate([x, y, 0])
                    cylinder(r=r, h=d, $fn=24);
    }
}

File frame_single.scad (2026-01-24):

// ============================================
// MODULAR CABLE ORGANIZER - SINGLE SLOT FRAME
// ============================================
// Simple frame with internal lip for snap retention
// Print flat side down (no supports needed)
// ============================================

include <parameters.scad>

// --- Main Module ---
module single_slot_frame() {
    outer_w = slot_width + (2 * frame_wall);
    outer_h = slot_height + (2 * frame_wall);
    
    difference() {
        // Outer body
        rounded_box_rect(outer_w, outer_h, frame_total_depth, 2);
        
        // Main slot cutout (from back to front)
        translate([0, 0, frame_back + slot_depth/2 + 0.1])
            cube([slot_width, slot_height, slot_depth + 0.2], center=true);
        
        // Back opening (smaller, for insert body to pass through)
        // Leaves material for snap tabs to catch on
        translate([0, 0, -0.1])
            rounded_box_rect(insert_body_width + 2*clearance, 
                            insert_body_height + 2*clearance, 
                            frame_back + 0.2, 1);
    }
}

// --- Utility: Rounded Box (rectangular) ---
module rounded_box_rect(w, d, h, r) {
    translate([0, 0, h/2])
        hull() {
            for (x = [-1, 1], y = [-1, 1])
                translate([x * (w/2 - r), y * (d/2 - r), 0])
                    cylinder(h=h, r=r, center=true);
        }
}

// --- Render ---
single_slot_frame();

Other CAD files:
print/print_insert_usbc_narrow.stl
print/print_insert_lightning_narrow.stl
print/print_frame_mixed_alternating_2rows.stl
print/print_insert_power_plug.3mf
frame_variable.scad
demo.scad
demo_mixed.scad
demo_universal.scad
insert_audio_jack.scad
insert_base.scad
insert_blank.scad
insert_blank_label.scad
insert_hdmi.scad
insert_lightning.scad
insert_universal_base.scad
insert_usb_b.scad
insert_usb_micro.scad
insert_usb_mini.scad
insert_usba.scad
insert_usbc.scad
main.scad
print/backup_unused/print_insert_audio_jack.stl
print/backup_unused/print_insert_blank.stl
print/backup_unused/print_insert_blank_label.stl
print/backup_unused/print_insert_blank_label_narrow.stl
print/backup_unused/print_insert_blank_narrow.stl
print/backup_unused/print_insert_lightning.stl
print/backup_unused/print_insert_micro.stl
print/backup_unused/print_insert_usb_b_narrow.stl
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

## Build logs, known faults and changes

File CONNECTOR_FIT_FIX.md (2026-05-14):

# Connector Opening Size Fix

## Issue
Lightning and Micro USB inserts had openings that were too small for the actual connectors.

## Root Cause
The dimensions in `parameters.scad` were incorrect based on actual connector specifications:

### Micro USB (USB Micro-B)
- **Old dimensions**: 6.9mm × 1.8mm
- **New dimensions**: 8.0mm × 2.8mm
- **Source**: Official USB-IF specification (Micro-USB Spec Rev 1.01)

### Lightning
- **Old dimensions**: 6.7mm × 1.5mm  
- **New dimensions**: 7.6mm × 1.5mm
- **Source**: Measured from actual Apple Lightning connectors

## Changes Made

### 1. Updated `parameters.scad`
- Line 70-74: Updated Micro USB dimensions from 6.9×1.8mm to 8.0×2.8mm
- Line 82-86: Updated Lightning dimensions from 6.7×1.5mm to 7.6×1.5mm

### 2. Created Test Print File
- **File**: `print_test_all_connectors.scad`
- **Contents**: All 7 connector types (excluding USB-C which already works)
  - Row 1: USB-A, USB Mini, USB Micro, USB-B
  - Row 2: Lightning, HDMI, 3.5mm Audio Jack

## USB-C Reference (Confirmed Working)
- **Dimensions**: 8.4mm × 2.6mm
- **Port clearance**: 0.1mm (applied to all connectors)
- This clearance provides a tight fit that works well

## Next Steps

1. **Generate STL**: Open `print_test_all_connectors.scad` in OpenSCAD and export to STL:
   ```
   File → Export → Export as STL
   Save to: print/print_test_all_connectors.stl
   ```

2. **Test Print**: Print all 7 inserts and test fit with actual cables

3. **Verify Fit**: Each connector should now have proper clearance:
   - Should insert smoothly without force
   - Should have minimal play/wiggle
   - Similar fit quality to USB-C

## Other Connector Dimensions (for reference)
All dimensions are from official specifications or measured from actual connectors:

- **USB-A**: 14.0 × 6.5mm (contact opening ~13.1 × 5.5mm spec + clearance)
- **USB Mini**: 6.9 × 3.0mm
- **USB-B**: 8.0 × 7.5mm (with beveled top)
- **HDMI**: 14.0 × 4.5mm (tapered shape)
- **3.5mm Audio**: 6.0mm diameter

## Port Clearance Philosophy
- All ports use `port_clearance = 0.1mm` (defined in parameters.scad line 11)
- This clearance is added via `offset(r=port_clearance)` in insert_base.scad
- Provides tight fit while allowing smooth insertion
- Tested and confirmed good with USB-C

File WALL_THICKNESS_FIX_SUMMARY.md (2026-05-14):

# Frame Wall Thickness Fix - Summary

## The Problem
Your 2x2 frame had walls that were **too thin between the slots**:
```
Before: 0.5mm wall = ~1 layer with 0.4mm nozzle ❌
```
This would result in:
- Weak, flexible walls
- Potential breakage during use
- Poor structural integrity

## The Solution
Increased wall thickness to a proper structural value:
```
After: 2.4mm wall = 6 layers with 0.4mm nozzle ✅
```
This provides:
- Strong, rigid walls
- Durable construction
- Professional print quality

## What Changed

### 1. Core Parameter Update
**File:** `parameters.scad`
```openscad
// OLD: frame_wall = 0.5;   // Too thin!
// NEW: 
frame_wall = 2.4;   // 6 layers @ 0.4mm nozzle for strength
```

### 2. All Frame Files Updated
- ✅ `print_frame_2x2.scad` - Fixed with parametric calculations
- ✅ `print_frame_3x3.scad` - **NEW** 3x3 frame created
- ✅ `demo.scad` - Updated frame structure
- ✅ `print_test_set.scad` - Updated frame structure

### 3. Insert Clearances Preserved
All insert dimensions remain **unchanged**:
- ✅ Insert fit clearance: 0.3mm (intact)
- ✅ Back cutout clearance: intact
- ✅ Snap tab clearances: intact
- ✅ Port openings: unchanged

Your inserts will still fit perfectly!

## New Files Created

### Production Files
1. **`print_frame_3x3.scad`** ⭐ NEW
   - 3x3 grid = 9 slots
   - Same strong 2.4mm walls
   - Ready to print

### Test/Validation Files
2. **`print_frame_wall_test.scad`**
   - Quick visual test of wall thickness
   - Shows 2 adjacent slots with 2.4mm wall
   - Optional insert fit preview

3. **`print_frame_validation_test.scad`**
   - Comprehensive test suite
   - Wall cross-section view
   - Insert clearance validation
   - Frame size comparison (1x1, 2x2, 3x3)

### Documentation
4. **`UPDATES.md`** - Detailed technical documentation
5. **`README.md`** - Updated with current project status

## Frame Size Comparison

| Frame | Slots | Width | Height | Notes |
|---|---|---|---|---|
| 1x1 | 1 | ~48mm | ~32mm | Test frame |
| 2x2 | 4 | ~72mm | ~42mm | **Common size** |
| 3x3 | 9 | ~109mm | ~58mm | **NEW** Large grid |

*All frames now have 2.4mm walls between slots*

## Next Steps

### 1. Quick Validation (Recommended)
Open `print_frame_wall_test.scad` in OpenSCAD:
- Press F5 to preview
- See the 2.4mm wall between two slots
- Visual confirmation of improvement

### 2. Test Print (Optional)
If you want to validate before printing full frames:
- Export `print_frame_wall_test.scad` to STL
- Small, quick print (~10 minutes)
- Feel the wall strength

### 3. Production Printing
Your updated frames are ready:
- `print_frame_2x2.scad` - Fixed with strong walls
- `print_frame_3x3.scad` - New 3x3 option
- Export to STL and print!

## Technical Details

### Wall Strength Calculation
```
2.4mm ÷ 0.4mm nozzle = 6 layers (perimeters)
```
Industry standard: 3-6 layers for structural parts
✅ We're using 6 layers = excellent strength

### Frame Dimension Changes
The stronger walls make frames slightly larger:

**2x2 Frame:**
```
Old: ~69mm × ~40mm (0.5mm walls)
New: ~72mm × ~42mm (2.4mm walls)
```
Difference: +3mm width, +2mm height (minimal)

**3x3 Frame:**
```
New: ~109mm × ~58mm (2.4mm walls)
```

### Print Time Impact
Stronger walls = slightly longer print:
- 2x2 frame: +5-10% print time
- Well worth it for structural integrity!

## Questions?

### "Will my existing inserts still fit?"
✅ YES! All insert clearances are unchanged. The wall thickness only affects spacing between slots, not the slot interior.

### "Do I need to reprint everything?"
- Frames: Yes, reprint for proper strength
- Inserts: No, existing inserts are fine

### "Can I adjust the wall thickness?"
Yes! Edit `frame_wall` in `parameters.scad`:
- Minimum recommended: 1.6mm (4 layers)
- Current setting: 2.4mm (6 layers) ✅
- Maximum practical: ~3.0mm (before slots get too tight)

---

**Summary:** Your frames now have proper structural walls (2.4mm) while maintaining all insert clearances. You have new test files for validation and a new 3x3 frame option ready to print!

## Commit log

2026-01-24 init commit
    [demo.scad, frame_single.scad, insert_audio_jack.scad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]
2026-01-26 v1 completed ready to print after creating back
    [demo_universal.scad, insert_base.scad, insert_universal_base.scad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]
2026-03-07 update latest stuff
    [insert_base.scad, parameters.scad, print_insert_mount.scad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]
2026-05-14 updated frames
    [frame_module.scad, print_frame_10x10.scad, print_frame_10x20.scad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]
